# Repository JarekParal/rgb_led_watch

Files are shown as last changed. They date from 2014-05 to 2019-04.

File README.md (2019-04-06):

# rgb_led_watch

RGB LED watch base on intelligent LED WS2812.

[Presentation video](https://youtu.be/sHXETtNtYNM)

License: [CC BY-SA 4.0](https://creativecommons.org/licenses/by-sa/4.0/?)

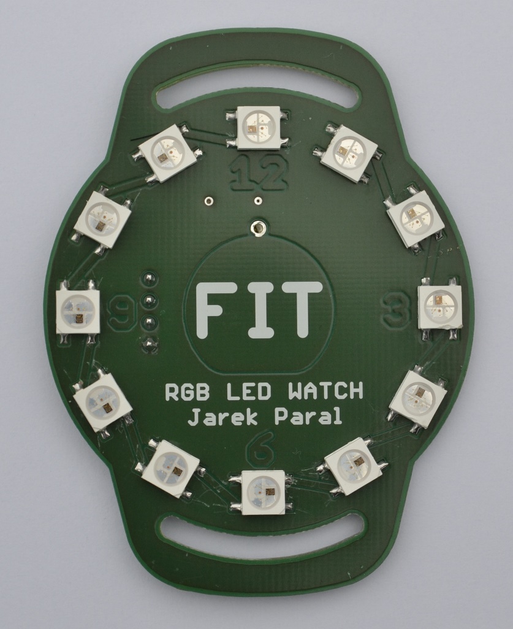
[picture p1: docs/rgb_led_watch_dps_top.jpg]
rgb_led_watch - top
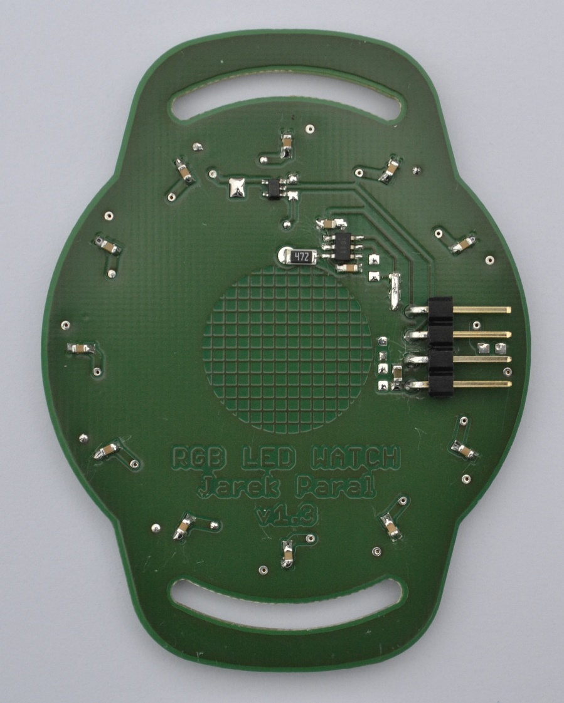
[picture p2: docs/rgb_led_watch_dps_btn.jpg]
rgb_led_watch - bottom
 
  
## Schema

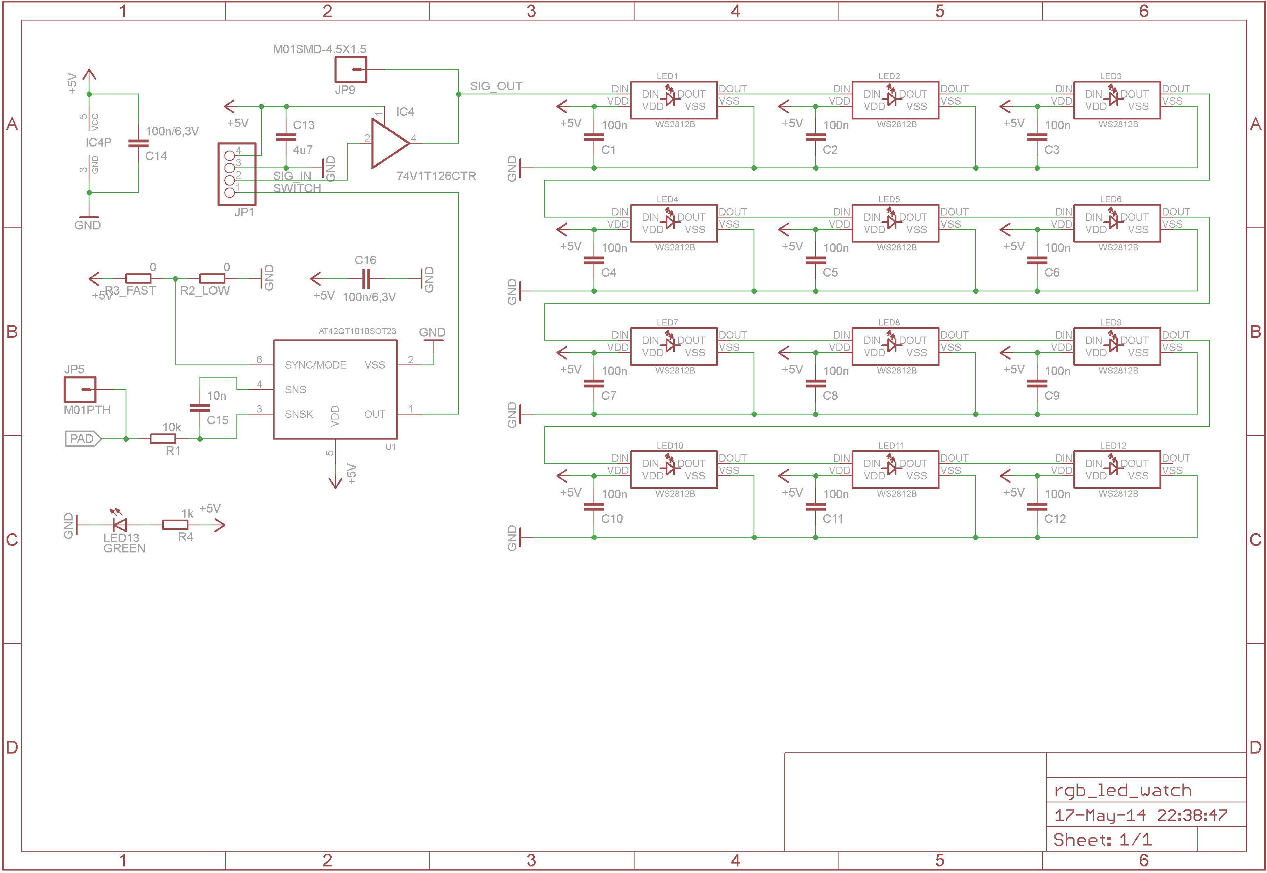
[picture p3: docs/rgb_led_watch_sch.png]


## Board

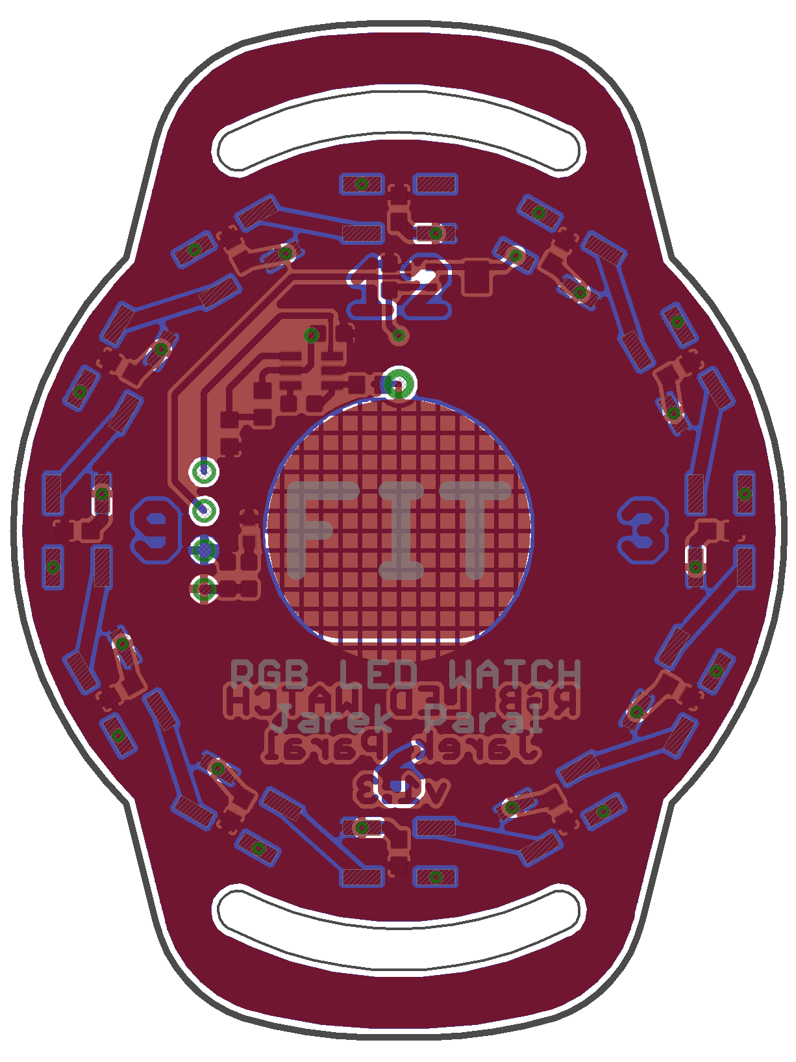
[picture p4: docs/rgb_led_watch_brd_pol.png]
rgb_led_watch - board - pol
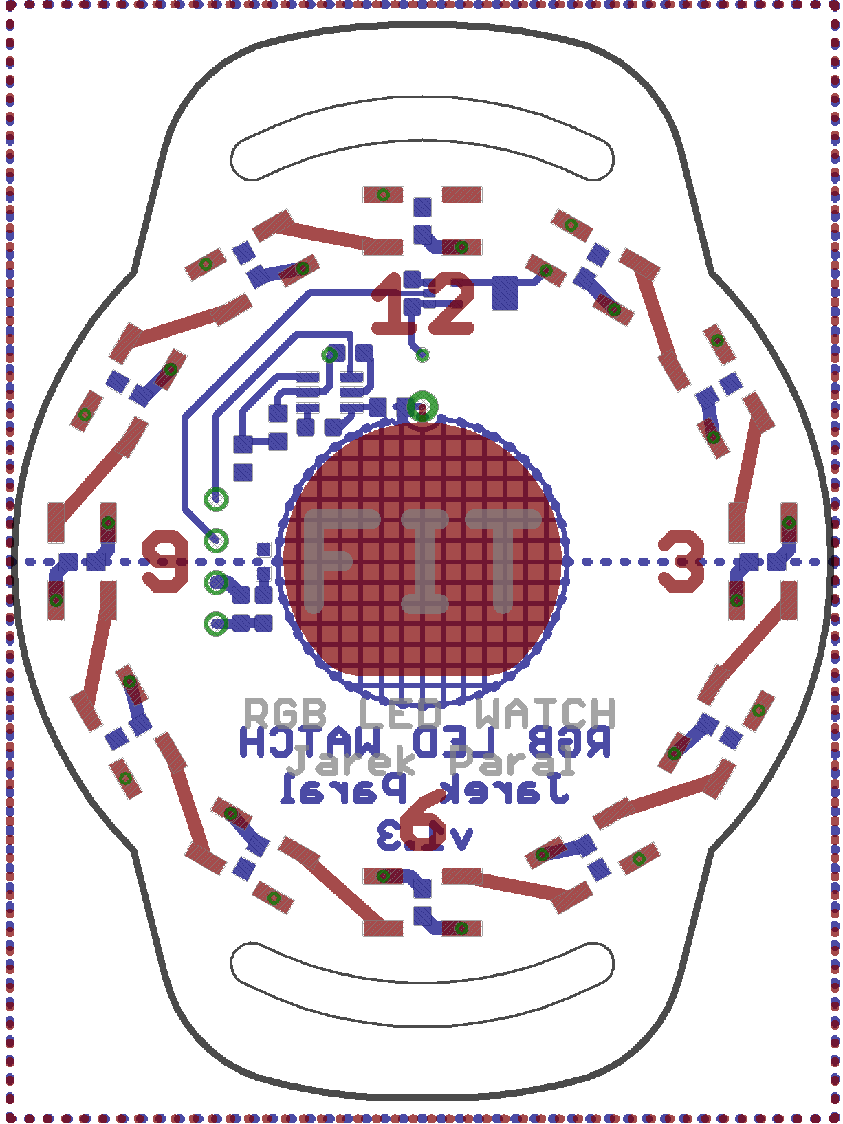
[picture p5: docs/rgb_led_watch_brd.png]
rgb_led_watch - board
  

## Other photos

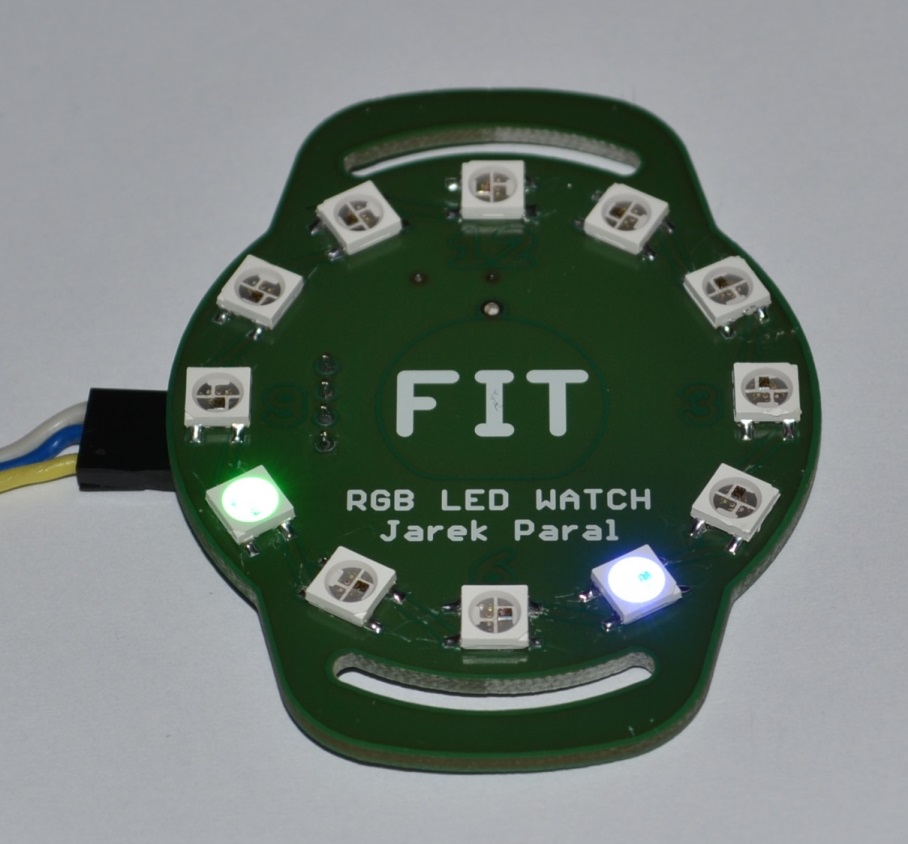
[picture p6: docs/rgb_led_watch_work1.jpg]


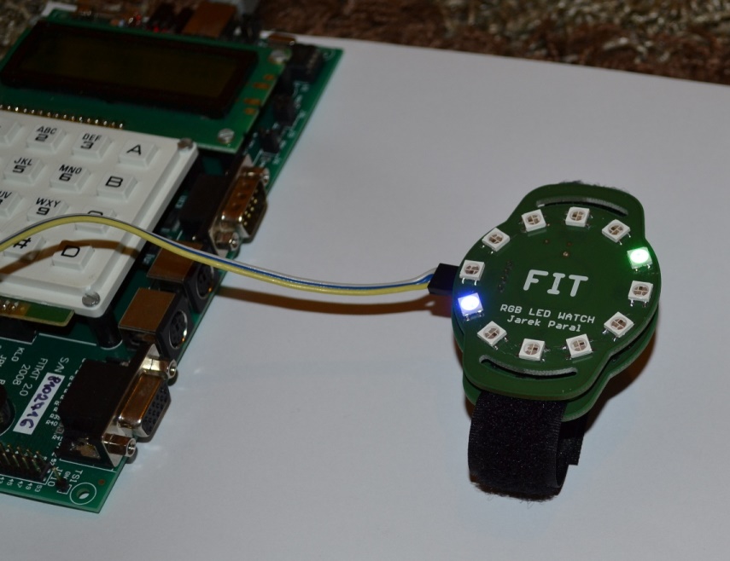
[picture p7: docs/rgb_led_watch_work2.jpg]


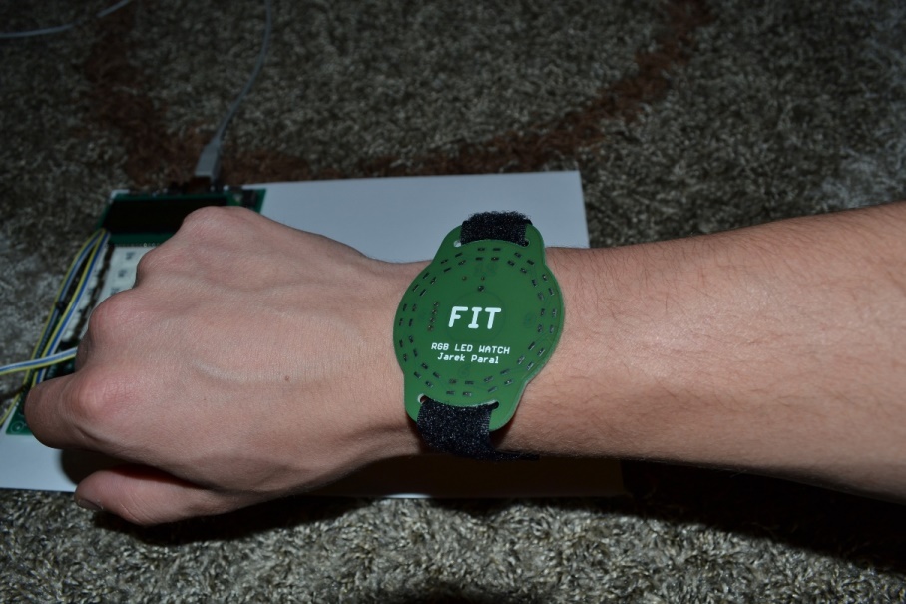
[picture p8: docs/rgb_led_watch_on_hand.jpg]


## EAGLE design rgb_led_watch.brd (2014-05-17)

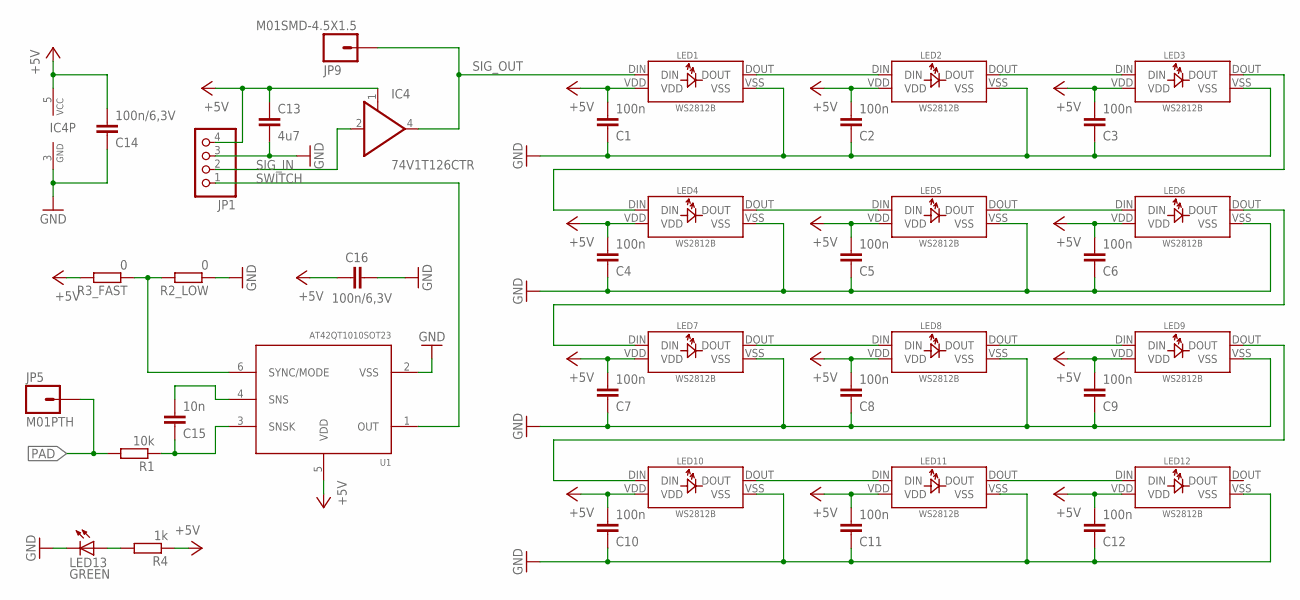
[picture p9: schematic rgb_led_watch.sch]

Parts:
C1, C2, C3, C4, C5, C6, C7, C8, C9, C10, C11, C12: 100n; C0603
C13: 4u7; C0603
C14, C16: 100n/6,3V; C0603
C15: 10n; C0603
IC4: 74V1T126CTR; SC70-5
JP1: PINHD-1X4/90; 1X04/90
JP5: M01PTH; 1X01
JP9: M01SMD-4.5X1.5; PAD-1.5X4.5
LED1, LED2, LED3, LED4, LED5, LED6, LED7, LED8, LED9, LED10, LED11, LED12: WS2812B
LED13: GREEN; CHIPLED_0603
R1: 10k; R0603
R2_LOW, R3_FAST: 0; R0603
R4: 1k; R0603
U1: AT42QT1010SOT23; SOT23-6

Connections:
+5V: C1.2, C2.2, C3.2, C4.2, C5.2, C6.2, C7.2, C8.2, C9.2, C10.2, C11.2, C12.2, C13.1, C14.2, C16.1, IC4.1 (OE), IC4.5 (VCC), JP1.4, LED1.VDD, LED2.VDD, LED3.VDD, LED4.VDD, LED5.VDD, LED6.VDD, LED7.VDD, LED8.VDD, LED9.VDD, LED10.VDD, LED11.VDD, LED12.VDD, R3_FAST.2, R4.1, U1.5 (VDD)
GND: C1.1, C2.1, C3.1, C4.1, C5.1, C6.1, C7.1, C8.1, C9.1, C10.1, C11.1, C12.1, C13.2, C14.1, C16.2, IC4.3 (GND), JP1.3, LED1.VSS, LED2.VSS, LED3.VSS, LED4.VSS, LED5.VSS, LED6.VSS, LED7.VSS, LED8.VSS, LED9.VSS, LED10.VSS, LED11.VSS, LED12.VSS, LED13.C, R2_LOW.1, U1.2 (VSS)
LED1: LED6.DOUT, LED7.DIN
LED2: LED9.DOUT, LED10.DIN
LED3: LED3.DOUT, LED4.DIN
unnamed: LED13.A, R4.2
unnamed: LED1.DOUT, LED2.DIN
unnamed: LED4.DOUT, LED5.DIN
unnamed: LED2.DOUT, LED3.DIN
unnamed: LED5.DOUT, LED6.DIN
unnamed: LED7.DOUT, LED8.DIN
unnamed: LED8.DOUT, LED9.DIN
unnamed: LED10.DOUT, LED11.DIN
unnamed: LED11.DOUT, LED12.DIN
PAD: JP5.1, R1.2
SIG_IN: IC4.2 (I), JP1.2
SIG_OUT: IC4.4 (O), JP9.P$1, LED1.DIN
SNS: C15.2, U1.4 (SNS)
SNSK: C15.1, R1.1, U1.3 (SNSK)
SWITCH: JP1.1, U1.1 (OUT)
SYNC_MODE: R2_LOW.2, R3_FAST.1, U1.6 (SYNC/MODE)

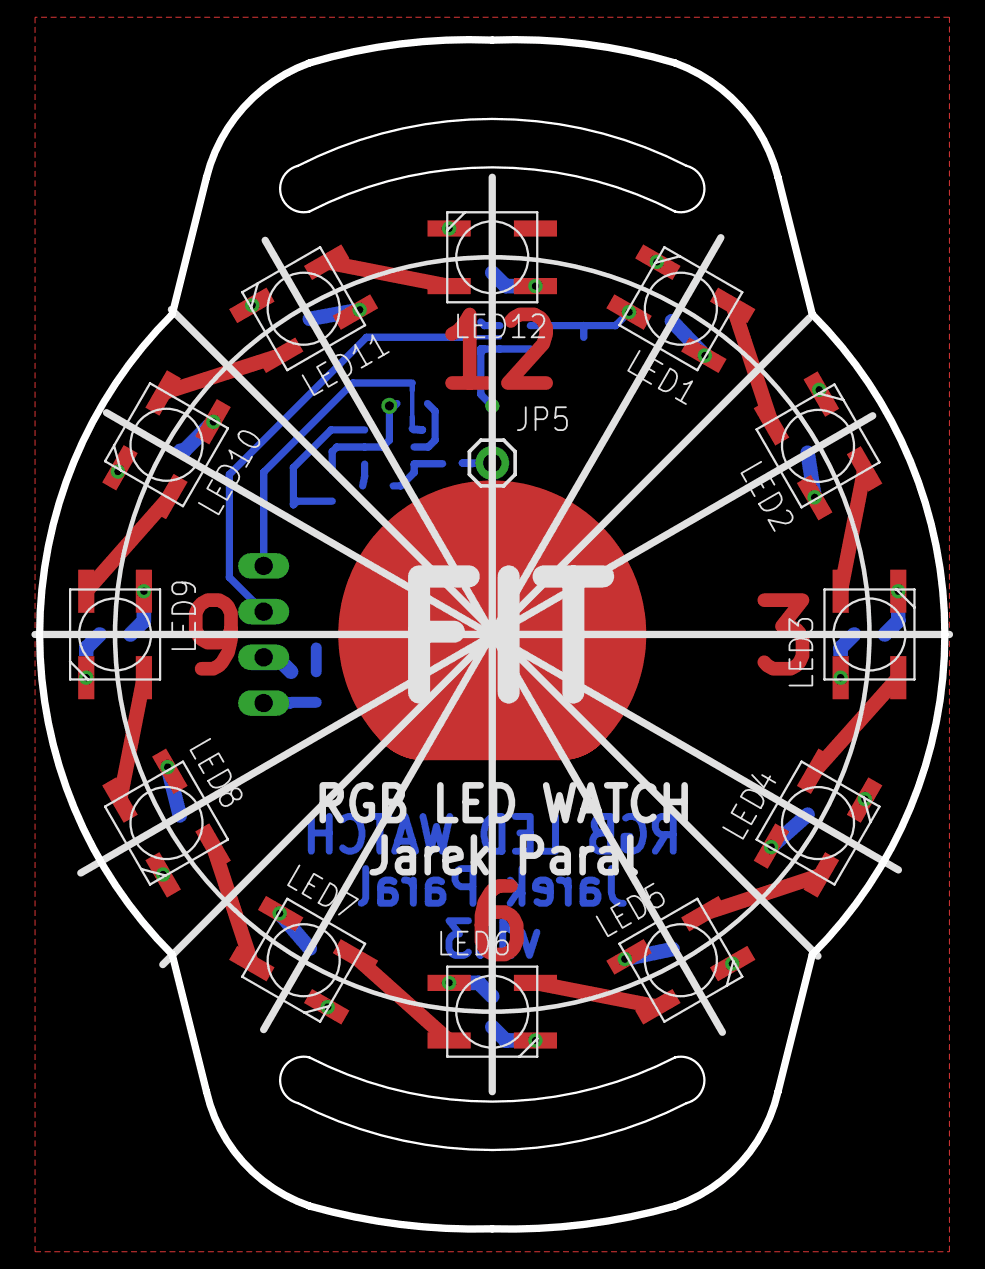
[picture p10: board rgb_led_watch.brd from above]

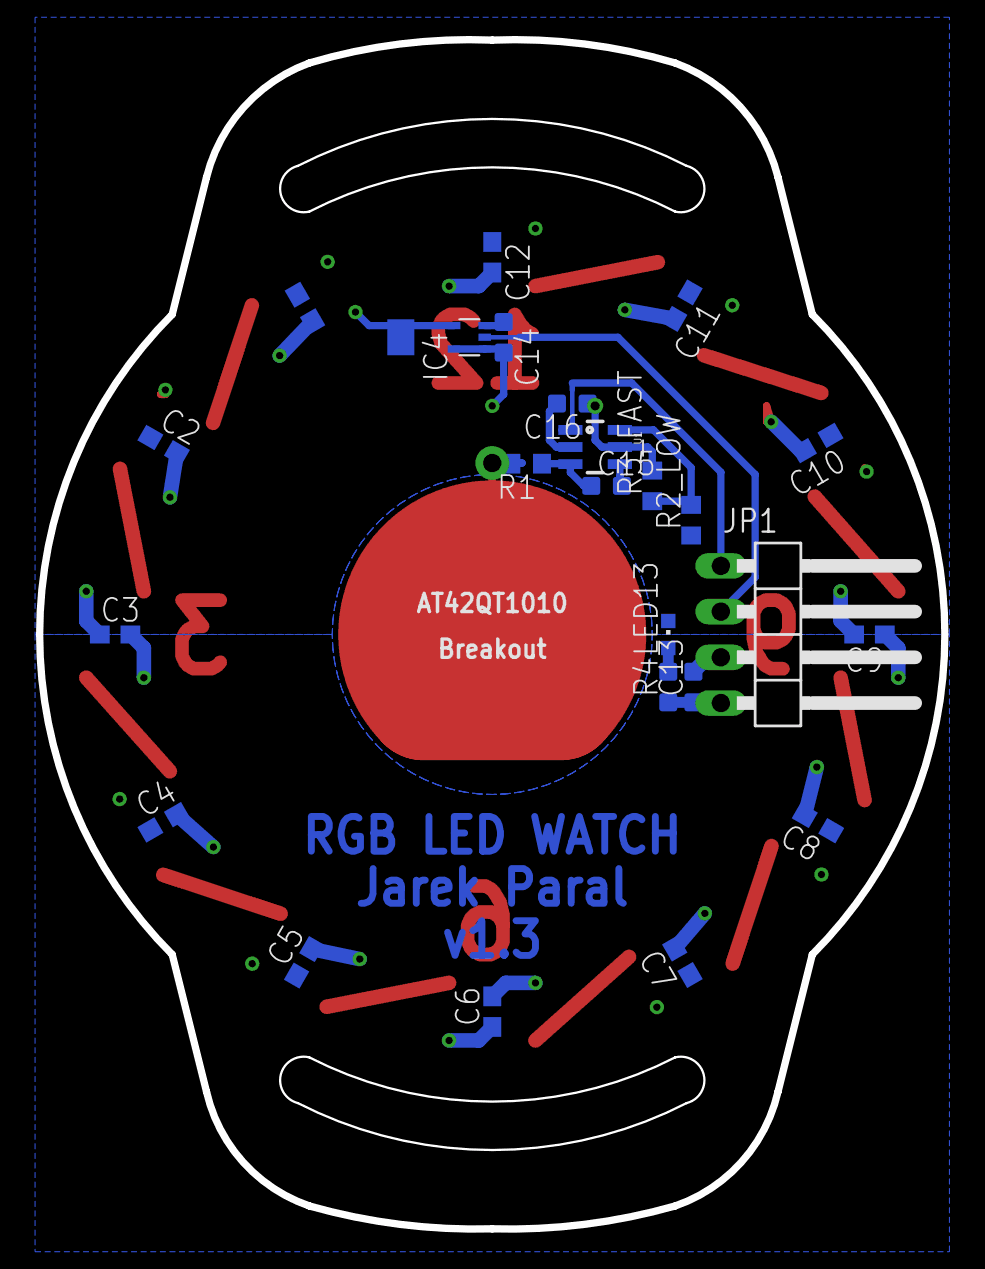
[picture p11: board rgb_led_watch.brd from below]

Board: 2 copper layers, 50.3 x 66.1 mm, 38 parts (25 on the bottom side), 21 nets.

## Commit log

2014-05-16 v1.0: prvni verze RGB LED hodinek (bez kapacitniho senzoru)
    [rgb_led_watch.brd, rgb_led_watch.sch]
2014-05-17 v1.1: opraveny chyby (nezaroutovana draha, spatne nastaveni polygonu)
    [rgb_led_watch.brd]
2014-05-17 v1.2: pridan kapacitni senzor
    [rgb_led_watch.brd, rgb_led_watch.sch]
2014-05-17 v1.3: upraven tvar do podoby hodinek (pridelany ouska) - pripraveno do vyroby
    [rgb_led_watch.brd, rgb_led_watch.sch]

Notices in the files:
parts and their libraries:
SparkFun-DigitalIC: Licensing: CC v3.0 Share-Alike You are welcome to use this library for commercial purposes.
